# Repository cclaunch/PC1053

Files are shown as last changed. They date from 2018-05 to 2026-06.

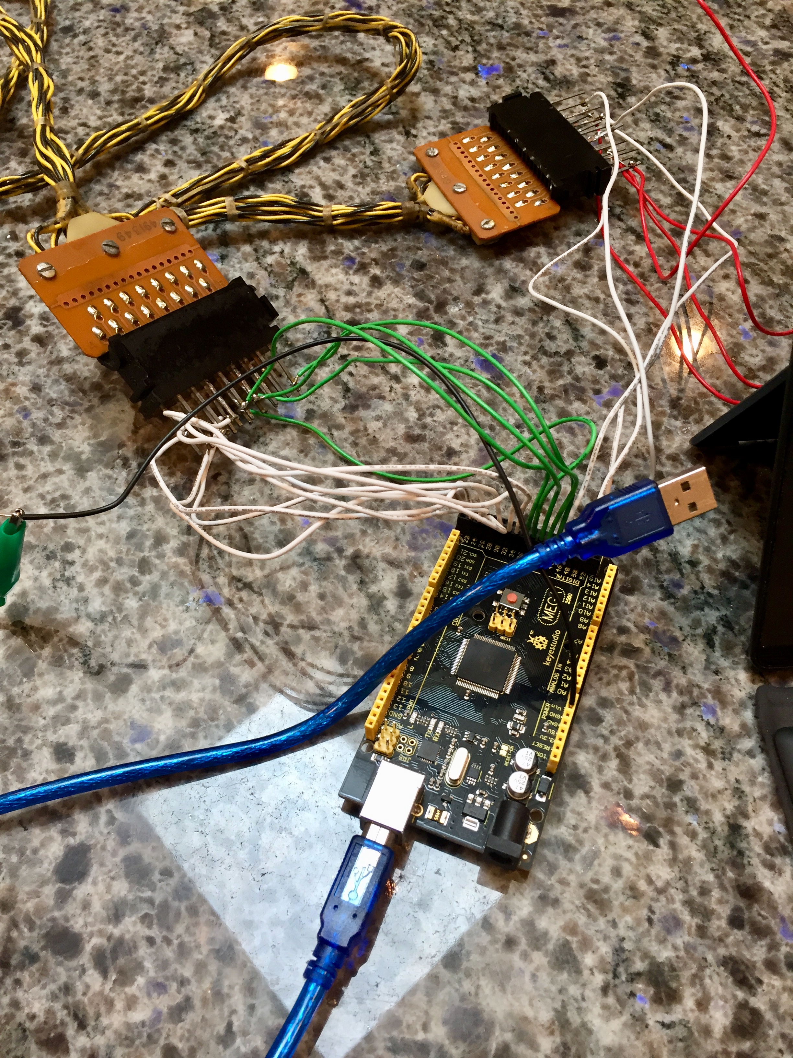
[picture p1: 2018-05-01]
testdriver quick and dirty.jpg

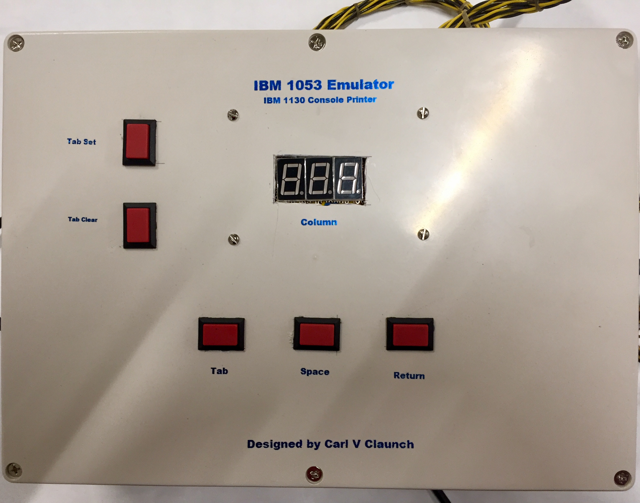
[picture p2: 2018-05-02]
example implementation.jpg

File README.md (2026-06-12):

# PC1053
Emulates an IBM 1053 (print-only I/O Selectric) as used on IBM 1130 and other mainframes of the 1960s

The 1053 attaches to a mainframe with three SMS paddle cards - two carry signals and the third delivers power. This emulator is built around an Arduino Mega 2560 R3, a relay module and some simple circuitry, hooked to three SMS paddle cards. It provides a serial port connection over a USB cable for communicating with a terminal emulator program on a personal computer to display the output that is being 'typed' by the mainframe. 

This emulates the console typeball that is installed on an IBM 1130 system, as well as the APL type ball (988), but can be easily modified to support additional typeballs. The normal typeball has characters that are not in standard ASCII, e.g. ¬ (logical not) and ¢ (cent sign) which can be displayed in UTF8. The APL typeball has many unique characters, thus needs the APL385 Unicode font on the terminal displaying the output. When using the APL typeball, the program looks for eighteen cases where APL software will overtype, using two characters from the typeball with a backspace between them, to form one composite character on paper; the program displays the resultant character instead of the pair. 

Using a terminal emulator that supports UTF8 encoding and ANSI colors provides the most realistic output, since the text will display in either black or red on white background - the text color is selectable by ribbon shift commands from the mainframe to the 1053. The terminal emulator provides a few commands that can be issued to the PC1053 - mainly to set the left and right margins, but also to set, clear and display tab stops that will be in effects and to switch between the normal and APL typeballs. I have found good results using Putty. 

PC1053 operates at approximately the same timing as a 1053, which supported a maximum of 15.5 characters per second and with the high speed carrier return feature would move from right to left edge in just a bit over 1 second. This provides realistic timing on the feedback signals that tell the mainframe when the Selectric mechanism is busy in a print cycle or performing an operation such as shifting case or moving to a new line. 

The device is constructed in a case with a three digit display to show the current column that the typeball/carrier has reached. It has buttons on the front to match the controls on a real 1053 - buttons to Tab, Space and Return, plus tab Set and Clear. This project has a Fritzing diagram of the connections and other circuits, while the physical layout of the case is left as an exercise for the reader. Four MOSFET and transistor circuits are needed to switch the +12V and +48V used with the four feedback signals from the typewriter to the IBM 1130.

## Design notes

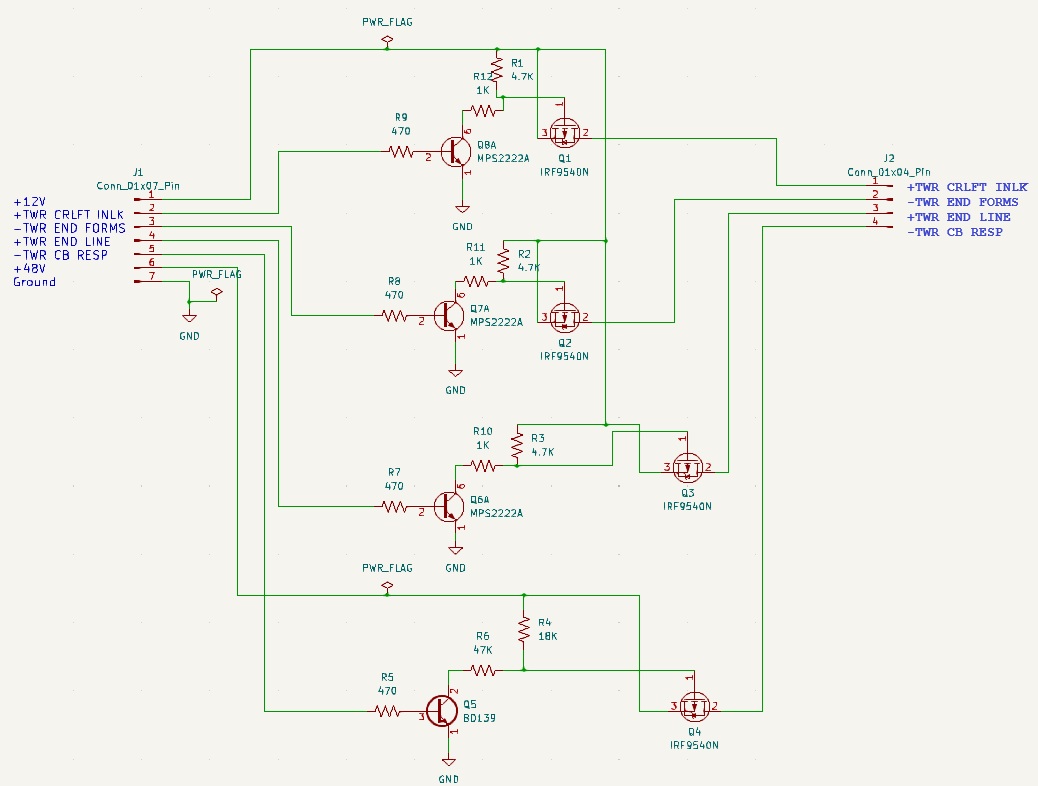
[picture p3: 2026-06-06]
MOSFET schematic.jpg

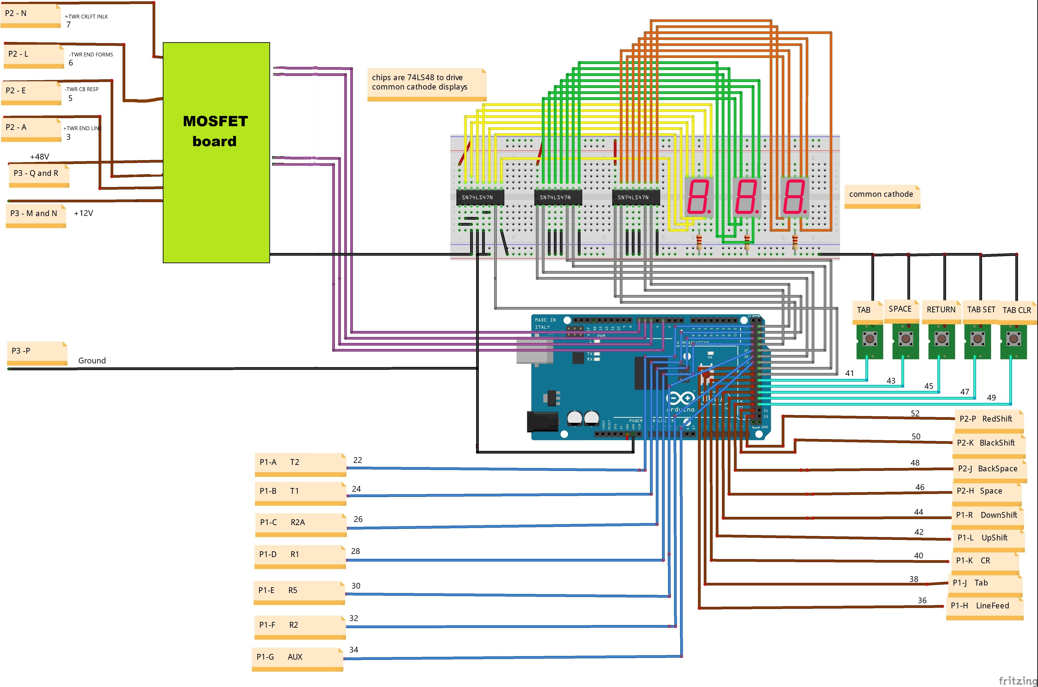
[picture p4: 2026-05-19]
pc1053.jpg

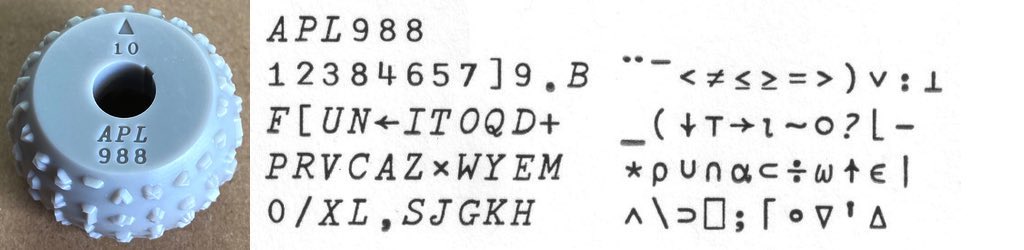
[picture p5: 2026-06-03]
APL988.jpg

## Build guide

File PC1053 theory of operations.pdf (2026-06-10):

## Theory of Operation

1053 Emulator for IBM 1130

Carl V Claunch | 1 | Version 1

Summary

This project created a box that plugs into the IBM 1130 in the place of the 1053 Console Printer that is built into the IBM 1130 System. The box connects via a USB serial cable to a Windows PC running the Putty emulator program.

The Putty program displays all the output exactly as it would appear on the paper in the 1053 printer. It also saves the output in a log file if hardcopy is desired.

The 1053 Emulator is designed to mimic all the behaviors and output of the console printer. The box that contains the emulator provides a three digit display to show the column where the carrier is sitting, buttons to request Return, Tab and Space, and buttons to set or clear a tab stop at the current column.

The other actions that a user could perform on the real 1053 are changing the left and right margins, or switching the golf-ball type element. The margins are changed by typing a command from Putty to the 1053 Emulator

The usual type element for the 1130 is number 969, but ball number 988 can be installed to use the 1130 to run the APL (A Programming Language) system. Another command can be entered through Putty to swtich between the type balls.

1053 Emulator for IBM 1130

Carl V Claunch | 2 | Version 1

The 1053 Console Printer

The console printer is a print only I/O Selectric typewriter. Solenoids are added to the Selectric typewriter mechanism to drive the mechanism. A set of solenoids trigger the following actions:

Space
Backspace
Carrier return/line feed
Line Feed
Tab

Another set of solenoids operate the character selection logic that determine how the ball tilts and rotates to pick one of 44 positions on the gold ball hemisphere. There are two that choose among the four rows of characters - Tilt 1 and Tilt 2. Four select the rotation among 11 columns on the ball - R1, R2, R2A and R5. A final solenoid called Aux is triggered with every request to type a character.

Another two solenoids control the shift mechanism, which spins the golf ball 180 degrees between the two hemispheres. On an office typewriter these are the upper case and lower case characters.

A final two solenoids select the ribbon color, choosing between typing on the upper half of the ribbon or the lower half - as the ribbon is bicolor with red and black ink

Microswitches are also added to the Selectric mechanism to provide feedback to the 1130 about the state of the typewriter. These combine to generate two key feedback signals that indicate when it is safe to request new printing or movement commands as well as when long operations like carrier return have completed.

1053 Emulator for IBM 1130

Carl V Claunch | 3 | Version 1

The Selectric mechanism is motor driven but uses clutches to fire off cycles when it is printing or moving. A print cycle is a 180 degree rotation of the main shaft which occurs when the character selection solenoids activate, moving the ball and flinging it forward to strike the paper through the ribbon.

In addition to typing a character, a 180 degree spin of the operational shaft cycle is used to operate the shift mechanism. When the next character to type is on the other hemisphere, one cycle is required to shift and then a subsequent print cycle does the actual printing of the carrier.

Movements that have a fixed time to operate also take a 180 degree turn of the operational shaft to complete. These are space, backspace and starting a tab movement.

Line feed requires a 360 degree rotation of the operatonal shaft, thus it is considered a long operation. Both tab movement and a carrier return require a variable amount of time to complete, depending upon the starting and ending column for the movement. These are also long operations.

-TWR CB RESPONSE is activated during the short operations and indicates the times when the mechanism is busy and cannot safely accept another request for movement or to type another character. A microswitchon the print cycle shaft opens during part of the rotation. Microswitches on the rear connected to the space and to the backspace mechanisms open while those are occuring. Finally, a microswitch on the mechanism that latches the carrier free so that it can begin a tab movemement will signal that the machine is busy starting to move. ‘

+TWR CRLFT INLK is activated during the long operations. Once the tab has begun and the carrier is latched free of the teeth so it can move, a microswitch on the latch keeps this signal active until the carrier rams into a tab stop which resets the latch as it stops. A microswitch on the

1053 Emulator for IBM 1130

Carl V Claunch | 4 | Version 1

carrier return mechanism latch is turned on when the mechanism latches the return, which drives the carrier to the left under power. When the carrier reaches the left margin, this disconnects the latch and releases the microswitch.

Two additional microswitches activate the signal at the start when the solenoid that requests line feed, carrier return or tab is first triggered, which blocks further requests from the 1130 during the early part of the long operations, until those latches on the return and on the tab mechanisms are active.

Two additional feedback signals are produced. One indicates that their is paper loaded into the typewriter, with a microswitch that the paper holds down. This is -TWR END FORMS. Lastly, a microswitch on the right margin stop is activated when the carrier reaches the right margin position, generating +TWR END LINE to trigger an automatic command from the 1130 to return the carrier and feed a line.

The typewriter menchanism can print at a maximum rate of about 15.6 characters per second if the request for each character is presented by activating the solenoids before the print cycle rotation has come to a stop.

The feedback signal -TWR CB RESPONSE allows the 1130 to send the next request as soon as it is safe to do so, allowing the machine to take continuous rotations without having to start and stop at the 180 degree mark.

Whenever the next character is on a different hemisphere from the one before, a shift cycle has to occur which slows down the machine. The maximum rate can only be achieved with a stream of characters all on the same hemisphere.

1053 Emulator for IBM 1130

Carl V Claunch | 5 | Version 1

The printer uses paper forms with pin feed holes on the two edges, with the typewriter tractor mechanism moving the forms though the machine reliably. Boxes of paper forms in this size are no longer available.

The line width is 120 columns, although the user can adjust the left and right margins to a narrower range. An indicator on the front of the printer shows the current column where the carrier is sitting.

Like any Selectric based typewriter, it provides tab stops to allow the softare to move the carrier to predetermined columns. These are set or cleared by manually moving the carrier to the desired column then turning the lever on the front of the printer to set or clear the tab stop.

The front of the printer also has three buttons that allow the user to trigger a carrier return/line feed, tab the carrier to the next tab stop, or space the carrier one column to the right.

The front of the printer also hosts a set of 16 toggle switches, named the Console Entry Switches. These are not related to the console printer at all, other than being mounted on the printer’s front panel

1053 Emulator for IBM 1130

Carl V Claunch | 6 | Version 1

The 1053 Emulator hardware

The emulator is constructed around an Arduino Mega 2560 controller board. It detects the signals from the 1130 that fire the various solenoids and it generates the four feedback signals to the 1130.

The 1053 has 48V applied to one side of each solenoid and the other side is connected to the controller logic inside the 1130. The controller logic is like an open collector gate - it either grounds the signal or leaves it untouched.

This is fortunate, because the Arduino can connect to the same logic gates but use a pullup resistor to +5V instead of dealing with 48V. When the controller logic pulls a line to ground, the Arduino sees its value drop from logic high to logic low. No interface circuitry is required for all the solenoid signals.

The feedback signals, on the other hand, must deliver a higher voltage to a switch debouncer circuit in the 1130 controller logic. Three of the signals have +12V running through the microswtiches, but the -TWR CB RESPONSE microswitches are fed with 48V.

The Arduino cannot handle these voltages, so I have a switching board that is driven by a 0-5V Arduino output and controls a MOSFET switch which acts almost exactly like the microswithces. The only different is that there is no switch bounce. Four circuits switch the four feedback signals.

1053 Emulator for IBM 1130

Carl V Claunch | 7 | Version 1

The box also contains five pushbuttons hooked to the Arduino, to activate the Tab Set, Tab Clear, Return, Tab and Space functions. Finally, the box has a board that drives three seven segment displays, using BCD to 7 Segment decoder chips (74LS47) to produce the digits.

Cables run from the box to connect into the 1130. One cable brings signals to an SMS paddle card (PF1), another cable brings signals to an SMS socket (PF2). The third is an SMS power paddle card that would deliver multiple voltages to the 1053. We ignore the 120V that the typewriter needs for its motor, but do use the +48V, +12V and ground lines.

1053 Emulator for IBM 1130

Carl V Claunch | 8 | Version 1

High level view of the Arduino code

The main loop first checks to see if data is arriving over the USB serial link, which it assembles until we reach eight bytes with a newline at the end. This is interpreted and if it is validly formatted, action is taken.

The valid incoming data can be a TS ###, TC ###, LM ###, or RM ### to set or clear tab stops or the left or right margin to column ###. Two other valid statements are TABS = and TYPE # which display all columns with tabs set or switches between type balls A or N.

All of the incoming signals from the 1130 controller logic are configured as inputs with a pullup resistor to 5V. The controller logic will pull the signal to ground to assert the request to activate a solenoid in the 1053.

Any request to type a character involves some number of selection solenoids being activated but always includes the AUX signal. Just as with the 1053 mechanism, the first selection signal that is asserted triggers a 65 millisecond print cycle.

The code waits until we are 5 ms into the print cycle so that other selection solenoid requests can arrive, as they might lag slightly from the first signal to be detected. At this time, the combination of selection solenoid requests is interpreted to determine what character on the type ball is to be printed.

1053 Emulator for IBM 1130

Carl V Claunch | 9 | Version 1

The selection solenoids T2, T1, R1, R2, R2A, R5 and AUX are used to look up an index in a tilt-rotate table.That index points to which of the 44 positions - four rows of tilt 0-3, eleven columns of rotate -5 to +5 - has the intended character.

Depending on which typeball (969 - normal, or 988 - APL) is installed and whether the ball is turned to the upper case or lower case hemisphere, we look in one of four character tables to pick up the unicode character.

At specific times in the 65 ms print cycle, the feedback signal -TWR CB RESPONSE is asserted and then deasseerted. The unicode character we picked up from the tables is stored in a line buffer at the current column position of the typeball carrier.

When we begin a new line we zero out a buffer that has entries for all 120 columns that can be typed upon by the 1053.

This buffer exists to support overtyping, where characters are typed in a column more than once. If the second character typed in the same column are different, then the ‘ink’ from each is left on the paper which forms a composite impression.

When using the APL type ball, we support overtyping for eighteen known cases that APL software produces. Otherwise, backspacing and then typing a character simply replaces the old with the new. The composite characters produced are:

⍱⍲⍒⍋⌽⍉⊖⍟⌶⍫⍎⍕⍀⌿⍝⍞!⌹

1053 Emulator for IBM 1130

Carl V Claunch | 10 | Version 1

Composite impressions can be used to obscure sensitive data, for example, but they can also be used to form a character that does not exist on the type ball. With only 88 positions on a type ball, 36 of which are necessary just to cover the alphabet and numeric digits, composite characters may be needed to support a broad character set requirement for some software that exceeds the capacity of a typeball.

Thus, every time we print at a column, the character is added to the buffer if it was empty. If the buffer already recorded a character had been previously printed there, we can check for the eighteen special cases.

The way that an overtype is accomplished on the 1053 is to use the backspace movement to shift the typeball carrier leftward to lower numbered columns up to the minimum of the left margin column. Then the additional character is typed.

When a space movement occurs with the 1053, it just moves one column to the right, leaving the paper underneath undisturbed. In the emulator, we have to print a space character the first time we reach a column moving from left to right, but if we had backspaced and then space forward, we do NOT want to blank out what was previously there.

The code checks the line buffer to see if anything had been printed in the column; if so, we just repeat typing the data in the buffer while we move the cursor one column forward.

1053 Emulator for IBM 1130

Carl V Claunch | 11 | Version 1

This supports the ability to edit a line by moving back and forward using backspace and space movement commands, leaving what is viewed on the screen appearing just as they were. Any typing that happens in a column where we previously typed is used to form a composite on the screen.

The movement requests space, backspace and tab will also kick off a print cycle of 65 ms, but without the AUX solenoid being fired, we don’t have a character to ‘type’ on the screen. We change the column where the typeball sits, retyping anything in columns we pass over, if characters had been typed there.

The code emits space and backspace characters to the terminal emulator program, or retypes a column, so that the screen matches what we would see on the paper on a 1053.

We use a fast search method to look at the byte array, 120 bytes for the 120 columns, searching for the first non-zero byte. That is the location of the next tab stop. We space over to that column to finish the tab movement or retype from the buffer as appropriate.

Solenoid assertions for carrier return/line feed, tab, or line feed also trigger a long cycle, which typically extends past the 65ms of the primary print cycle. At fixed times during the long cycle, the +TWR CRLFT INLK feedback signal is asserted and then deasserted.

1053 Emulator for IBM 1130

Carl V Claunch | 12 | Version 1

The time it will take to finish the long cycle depends on the operation and also both the current column number and the destination column number. A carrier return from the right side takes longer than if it is issued only ten columns to the right of the margin. A tab duration depends on how many columns we have to pass from the current column to the first one that has a tab stop set. Line feed takes a fixed amount of time to occur.

This is calculated when we start the long cycle and used to control the deassertion of the +TWR CRLFT INLK feedback signal

Activations for the Shift to Upper or Shift to Lower solenoids trigger a 65 ms print cycle, but without the AUX solenoid asserted, nothing is typed. We simply record the hemisphere that is reached as this is used during the character table lookups when printing.

Asserting the Shift to Red or Shift to Black solenoids does NOT trigger a print cycle or provide any feedback signals. It causes the code to send an ANSI Color sequence to the Putty terminal program which changes the text color to red or black.

On the 1053, the user slides levers to set the left and right margins. The left margin is the point where the typeball carrier stops when doing a carrier return. It is the point beyond which we cannot backspace. The right margin is where the +TWR END LINE feedback signal is asserted if the carrier reaches that column.

1053 Emulator for IBM 1130

Carl V Claunch | 13 | Version 1

The controller logic in the 1130 will immediately trigger a carrier return/line feed cycle by assering that solenoid when the end of line feedback signal is on. The controller marks the typewriter busy until the return has finished based on the feedback signal +TWR CRLFT INLK going low.

However, if the user somehow manages to drive print requests when we have reached the right margin, the code does not advance the column, it backspaces and erases whatever character we tried to type. This matches how the 1053 behaves in the same circumstances.

The last feedback signal from the 1053 that we control is -TWR END FORMS which is asserted low if the paper has run out on the 1053. The controller logic will not type or move the carrier when this is asserted and a FORMS CHECK lamp on the console of the IBM 1130 will illuminate..

If the 1053 Emulator is powered down, the 1130 system sees the -TWR END FORMS signal as asserted and lights the FORMS CHECK lamp. During the setup part of the code initialization, we deassert this, extinguishing the lamp.

1053 Emulator for IBM 1130

Carl V Claunch | 14 | Version 1

Special techniques used in the code

We make use of direct port register access rather than using the slower digitalRead and digitalWrite statements. Refer to a port map for the Arduino Mega 2560 to see which registers and bits of the Microchips ATmega2560 processor chip are associated with each of the Arduino pins.

I used the traditional Arduino statements to set the input or output mode for the pins, but then I directly access the ports to read or write. For a read, I examine the specific bit of the associated port, usng macros for readability:

#define readAUX !(PINC & (1<<3))

For writes, I either set or clear the specific bit in the associated register to set the Arduino pin high or low. I set up macros to do this, for example:

#define highEOL | PORTE |= (1<<5)

#define lowEOL | PORTE &= ~(1<<5)

Rather than looping through an array of 120 locations looking for the next tab stop, I used a fast search that moves through a byte array by fetching doublewords at a time until the doubleword is non-zero, then determining which of the bytes inside has the first non-zero value.

1053 Emulator for IBM 1130

Carl V Claunch | 15 | Version 1

I do make use of character pointer arithmetic to index into arrays, thus array[index] or array+index is equivalent. Unicode characters can take 1 to 4 bytes of storage, thus a character array such as the table of characters on the typeball is not simply 88 bytes long. The location of a specific character in the array is not simply an integer index.

In fact the index into the array is to a byte, not to character boundaries. For example, if the first three characters in the array are a four byte Unicode, a 1 byte Ascii and a four byte Unicode, then the index of the fourth character is 8 - there were nine bytes consumed for the first three characters.

I have some helper routines that will scan through a Unicode character array and return the byte index into the array of the nth character. Asking it for the fourth character would return a byte index 8 based on the example in the prior paragraph.

Another helper routine is given the starting byte in the character array and copies the character at its correct length into a temporary five byte long character field called tempchar which is zero terminated. Thus we always print using tempchar as it will have the proper length string of bytes for the Unicode character, anything from 1 to 4 with a terminating null character.

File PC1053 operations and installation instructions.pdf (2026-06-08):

## Operations and Installation Instructions

1053 Emulator for the IBM 1130

Carl V Claunch | 1 | Version 1

1053 Console Printer on the IBM 1130 System

The IBM 1130 System was announced and delivered in 1965. The system comes with a console that has a keyboard and a printer, along with controls and display lights. The console printer is a print only I/O Selectric typewriter.

The printer uses paper forms with pin feed holes on the two edges, with the typewriter tractor mechanism moving the forms though the machine reliably. Boxes of paper forms in this size are no longer available.

The line width is 120 columns, although the user can adjust the left and right margins to a narrower range. An indicator on the front of the printer shows the current column where the carrier is sitting.

As each character is typed the carrier advances to the right until it reaches the right margin, when a bell will ring and the 1130 will automatically move the carrier back to the left margin and advance the paper one position.

A type element (golfball) is installed on the carrier to provide the 88 characters that can be printed. The normal ball for the IBM 1130 is numbered 969 just under the top latch, although variations were used for some non-US customers.

The 1053 has a dual color ribbon, allowing the selection of either black or red type to be printed on the paper.. This is under software control.

Like any Selectric based typewriter, it provides tab stops to allow the softare to move the carrier to predetermined columns. These are set or cleared by manually moving the carrier to the desired column then turning the lever on the front of the printer to set or clear the tab stop.

1053 Emulator for the IBM 1130

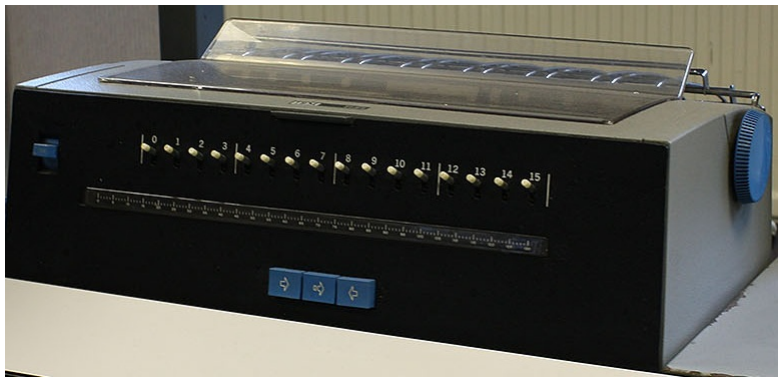
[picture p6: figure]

Carl V Claunch | 2 | Version 1

The 1053 has a high speed carrier return feature installed which returns from the right side to the left margin in roughly one second. Line feed operations move the paper up one or two lines at a time - selectable by a lever on the printer - in under a second. The typewriter can produce print at a rate of up to 15.6 characters per second.

The front of the printer also has three buttons that allow the user to trigger a carrier return/line feed, tab the carrier to the next tab stop, or space the carrier one column to the right.

The front of the printer also hosts a set of 16 toggle switches, named the Console Entry Switches. These are not related to the console printer at all, other than being mounted on the printer’s front panel

image modified from- Martin Skøtt -File:IBM 1130 concole.ms.jpg (https://commons.wikimedia.org/wiki/File:IBM_1130_concole.ms.jpg) [accessed 2026-06-05]. License/note: CC BY-SA 2.0.

Three cables run from the printer down through the 1130 to plug into connector blocks. Two are for the signals between the 1130 and 1053, the third carries power to the console printer.

1053 Emulator for the IBM 1130

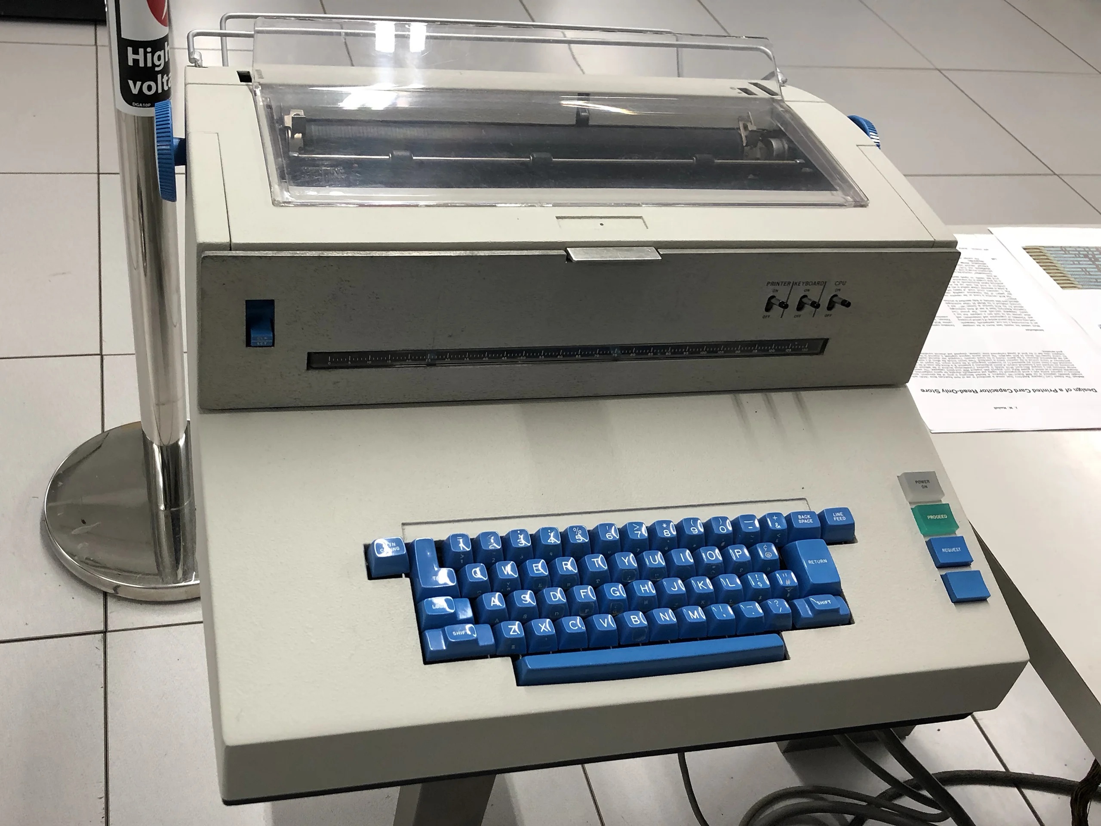
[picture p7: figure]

Carl V Claunch | 3 | Version 1

IBM used the same mechanism for the primary operator consoles of their System 360 mainframes, introduced at about the same time. That 1052 had a slightly different case, without the console entry switches of the 1130 and had a keyboard attached.

The keyboard was not a Selectric typewriter part, it was the keyboard used in the 029 Keypunch. It shared the case but was unrelated to the printer portion of the 1052. The same keyboard mechanism is on the IBM 1130 but not physically connected to the console printer.

image: ComputerGeek7066 - File:IBM 1052.jpg (https://commons.wikimedia.org/wiki/File:IBM_1052.jpg) [accessed 2026-06-05]. License/note: CC BY-SA 4.0 (cropped).

1053 Emulator for the IBM 1130

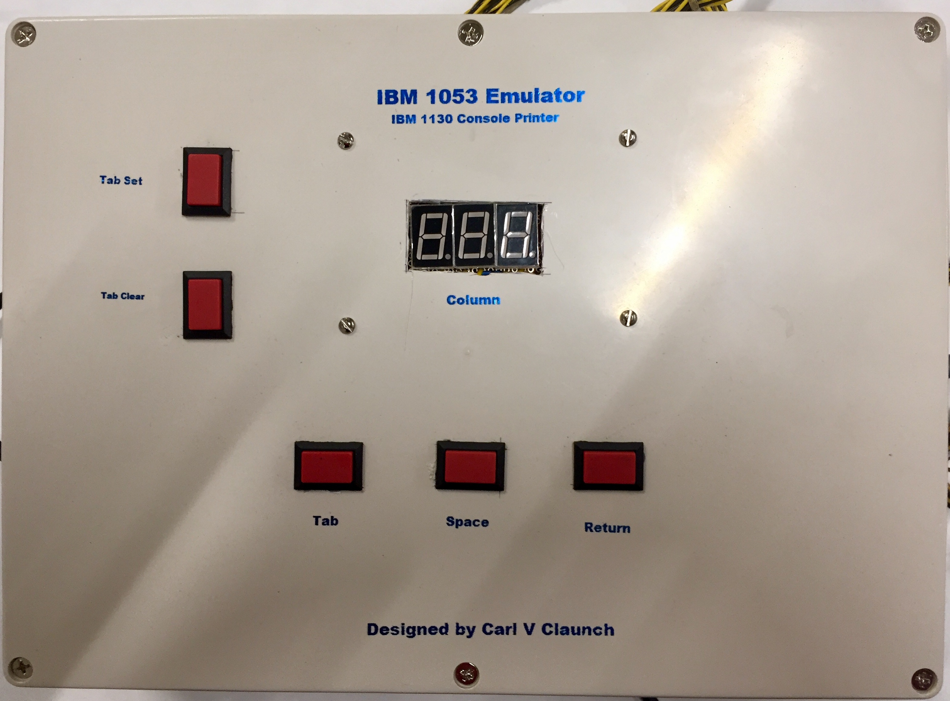
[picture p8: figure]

Carl V Claunch | 4 | Version 1

Overview of the 1053 Emulator

The emulator consists of a box that sits on top of the 1130 system and connected by a USB serial cable to a computer that runs a terminal program where the output of the console printer is displayed and recorded.

The box has a three digit display that shows the column where the carrier is sitting at the moment. Buttons across the bottom allow the user to command the printer to space one column to the right, move the carrier to the next column on the right that has a tab stop set, or to return the carrier to the left and advance the paper one line.

1053 Emulator for the IBM 1130

Carl V Claunch | 5 | Version 1

Buttons on the left will set or clear the tab stop at the current column as displayed on the three digit display. Other interactions are supported by commands through the USB serial cable.

A menu is printed when the emulator starts up, listing the commands that it will recognize when typed on the computer emulator program that displays the output.

The left and right margins are set by commands, otherwise they default to column 1 and column 120. The emulator program displays output in red or black text, based on how the 1053 would be typing at the moment.

For convenience, commands are provided to set or clear tabs by entering the column number, rather than having to space the carrier over to the desired column. Another command will display all the tabs that are set.

One additional type element can be used with the IBM 1130, to run
APL (A Programming Language). The ball has 988 on the top near the lever and contains the specialized characters that are used in APL. To switch between typeballs, the command TYPE # is issued, where # is N for the 969 ball and A for the 988 ball.

Some of the characters used in APL are composite, formed by typing one character from the ball, backspacing, and typing over it with another character from the ball. The display will show the composite character just as it would have been produced by ink overtyped on ink using paper in the 1053.

1053 Emulator for the IBM 1130

Carl V Claunch | 6 | Version 1

Starting the Putty emulator program

The 1053 Emulator has been tested with the free Putty terminal emulator running on Windows. It requires that the WIndows system has installed the free APL 385 Unicode truetype font, then configure the terminal to use that font.

Assuming you have configured Putty and saved the configuration, you load that saved config to start the program. The configrution also specifies that a log file is saved with the output. The file does not save colors but otherwise it will match the text shown on the screen.

Generally, the user will set the left and right margins via commands, set any tab stops expected by software and then start the 1130 software.

The 1053 Emulator is powered by the USB connection from the computer running Putty. When it is not on, the FORMS lamp on the 1130 will light, indicating that the 1053 is not able to print because it does not have paper loaded. As soon as the Emulator powers up, the FORMS lamp will turn off.

1053 Emulator for the IBM 1130

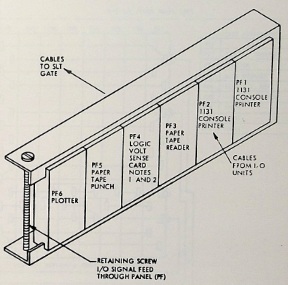
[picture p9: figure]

Carl V Claunch | 7 | Version 1

Installing the 1053 Emulator signal cables

Inside the 1130, the three cables from the 1053 printer are hooked to connector blocks. The upper connector block is where signals are connected from certain peripherals including the 1053. The lower connector block is where the power cables for the peripherals attach.

The devices that use these connector blocks are older designs that use the 1950s generation Standard Modular System (SMS) rather than the Solid Logic Technology (SLT) of the 360, 1130 and 1960s era devices.

The connector on the cable is an SMS paddle card, which has the same kind of pads on the end as SMS logic cards from machines like the 1401. A female version exists, which is the socket that the logic cards fit into, which can fit on the end of a cable instead of the paddle card. For the 1053, there are two signal cables. PF1 ends in an SMS paddle card (male) while PF2 has an SMS socket (female) on its end.

1053 Emulator for the IBM 1130

Carl V Claunch | 8 | Version 1

The signal connector block has assigned location for each peripheral, with the two rightmost locations used for the 1053. The rightmost postion has an adapter installed, so that the PF1 paddle card plugs into one side and a paddle card from the 1130 processor plugs into the rear side. The second position is where the PF2 SMS socket fits, with a paddle card from the 1130 plugged into the socket from the rear.

First, the SMS paddle card from the 1130 logic is pulled out of the PF2 SMS socket from the rear. We unplug the PF1 SMS paddle card from the adapter. The bolt on the left is removed and the PF2 SMS socket is slid out of the bracket to the left to remove the 1053 cables.

The 1053 Emulator PF2 SMS socket is slid into the bracket, the PF1 paddle card is inserted into the adapter in in the rightmost position, and the bolt is replaced in the connector block. The SMS paddle card behind the PF2 socket is inserted from the rear to complete the installation of the signal cables.

1053 Emulator for the IBM 1130

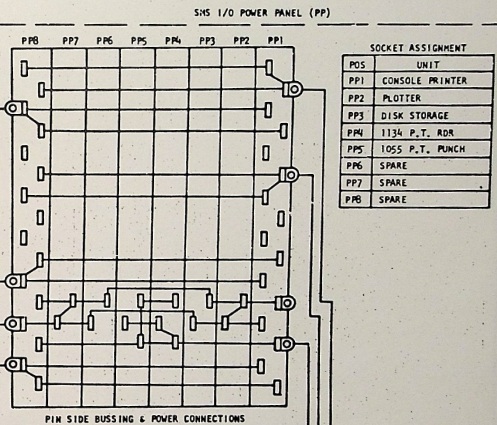
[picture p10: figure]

Carl V Claunch | 9 | Version 1

Installing the 1053 Emulator power cable

The power connections use a modified version of the SMS paddle card. These have larger combined pads to carry more current, as well as having a notch cut into them that blocks ordinary paddle cards from fitting into the power connector block. The power connector block has a metal bar across the span that prevents signal cards from being inserted.

The power connector block also has assigned locations for each device, with the 1053 assigned to the rightmost socket.

1053 Emulator for the IBM 1130

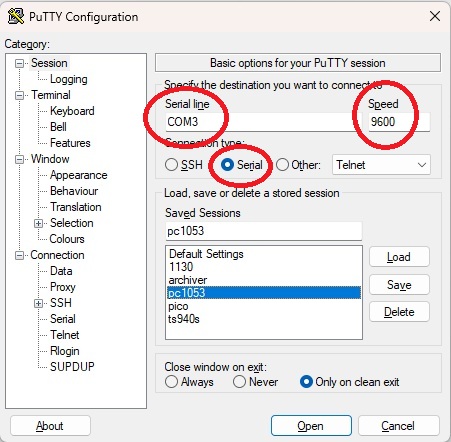
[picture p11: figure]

Carl V Claunch | 10 | Version 1

Configuration of Putty

On the main configuration screen, set the connection type to Serial, the speed to 9600 baud and use whatever COM port that the 1053 Emulator shows up with.

1053 Emulator for the IBM 1130

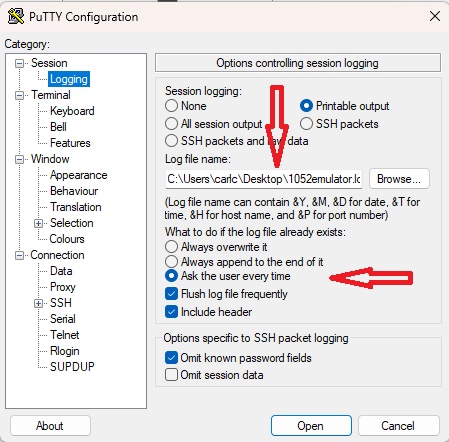
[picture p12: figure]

Carl V Claunch | 11 | Version 1

Next, go to the logging screen and choose a file location and name for the log file. Also select the option to ask the user for how to handle it when the log file already exists from a prior run. .

1053 Emulator for the IBM 1130

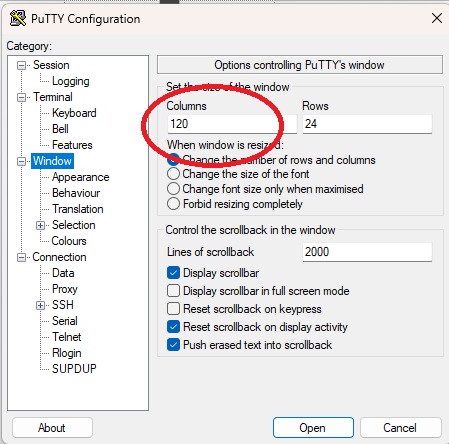
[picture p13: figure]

Carl V Claunch | 12 | Version 1

Select the Window category and configure the terminal to 120 column width.

1053 Emulator for the IBM 1130

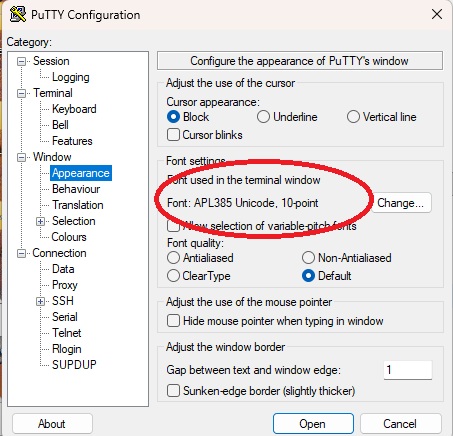
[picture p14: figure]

Carl V Claunch | 13 | Version 1

The appearance category is where you change the font for the terminal window to use the APL385 Unicode truetype font, at 10 point size.

1053 Emulator for the IBM 1130

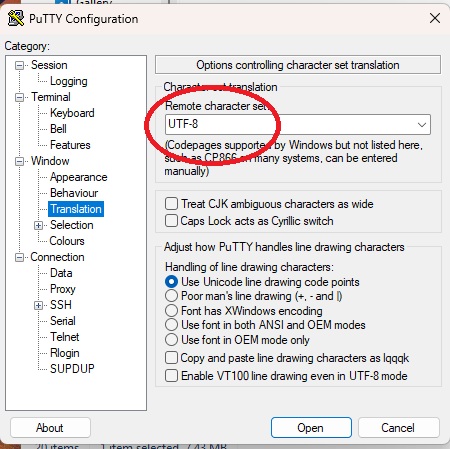
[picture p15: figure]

Carl V Claunch | 14 | Version 1

Configure the Translation category to set the character set to UTF-8 which is how the 1053 Emulator is emitting characters.

1053 Emulator for the IBM 1130

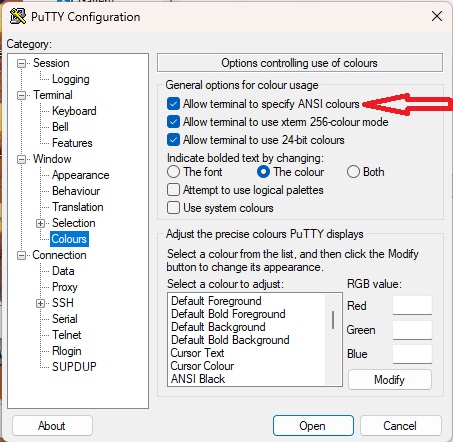
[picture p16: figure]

Carl V Claunch | 15 | Version 1

The Colors category should set the window to use ANSI Colors which is how the 1053 Emulator controls the text color.

1053 Emulator for the IBM 1130

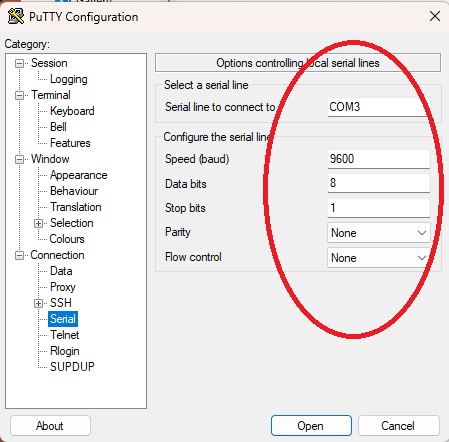
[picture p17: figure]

Carl V Claunch | 16 | Version 1

The final category to look at is Serial. Make sure that the link is set up for 9600 baud, 8 data bits, 1 parity bit, no parity and no flow control.

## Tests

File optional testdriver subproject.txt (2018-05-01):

Optional testbed for PC1053

Using a second Arduino Mega 2560 and some SMS sockets, you can use the testdriver.ino file and its Fritzing diagram to put the PC1053 through its paces without plugging into an actual mainframe. It provides the ability to send every command and character that the mainframe can produce; it even provides a 2 ms skew in setting of the tilt/rotate lines to verify that this device can handle slight variations in timing from the mainframe.

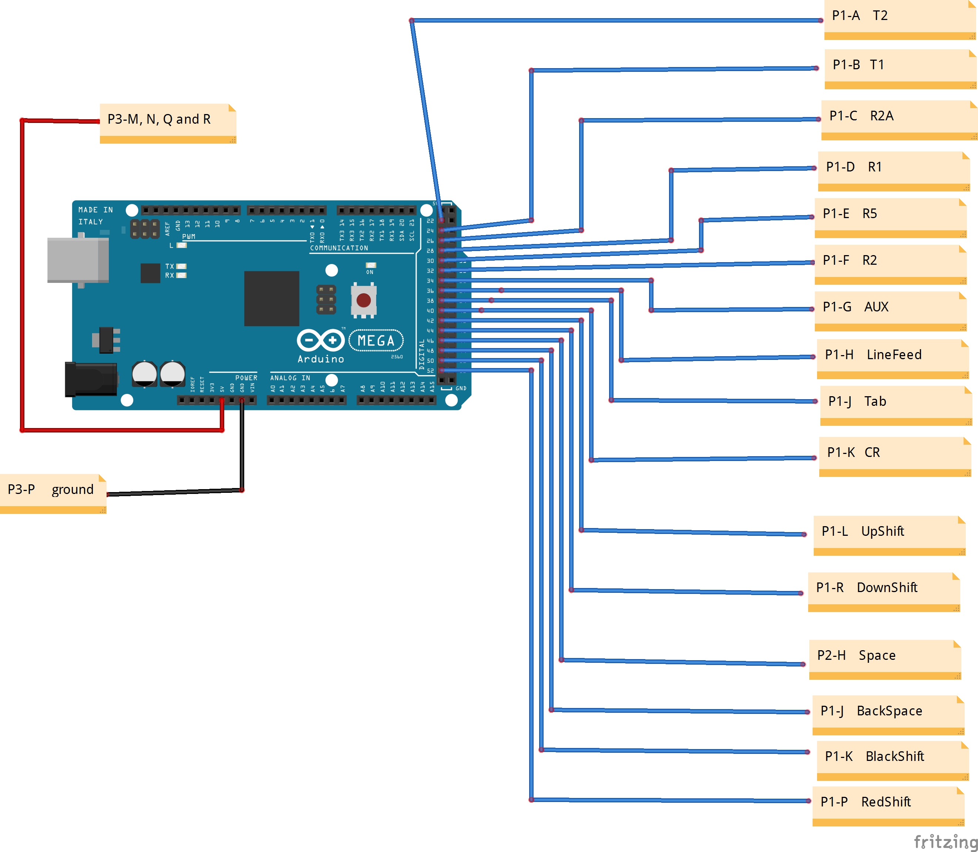
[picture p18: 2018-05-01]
testdriver.jpg

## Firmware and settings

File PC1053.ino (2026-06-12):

// PC1053 project to emulate an IBM 1053 Console Printer when hooked to an IBM 1130 or IBM 1800 computer system
//
//    Carl V Claunch
//
// repository on Github https://github.com/cclaunch/PC1053
//
// drives an Arduino Mega 2560 hooked to MOSFET switches, 7 segment display hardware, pushbuttons, and SMS style paddle
// connectors that plug into the 1130 or 1800. One of the paddle connectors provides power (ground, +12V and +48V) to
// the 1053, which is an I-O Selectric mechanism based around a Selectric 1 typewriter using solenoids and microswitches
// to interface it to a computer. Commonly used in the 1960s with the 1130, 1800 and as the main console for S/360 systems
//
// uses direct port access which ties this to the specific Arduino model (Mega 2560)
//
// connect via USB serial port at 9600 baud 8 n 1 1 using UTF-8 encoding and ANSI Colors
//
// supports simple commands from the serial terminal
//  LM nnn     
//       sets the column for the left margin
//
//  RM nnn
//       sets the column for the right margin
//
//  TS nnn
//       sets a tab stop at column nnn
//
//  TC nnn
//       clears a tab stop at column nnn
//
//       NOTE for all commands with nnn, a three digit column number with leading zeroes if needed
//
//  TABS =
//    displays all the column numbers where a tab stop is set 
//
//  TYPE t
//    switches between normal and APL typeball  NOT YET SUPPORTED
//    *******   t is either N for normal or A for APL typeball

#include <stdint.h>
#include <stddef.h>

// global defines
#define SelectT2      22
#define SelectT1      24
#define SelectR2A     26
#define SelectR1      28
#define SelectR5      30
#define SelectR2      32
#define SelectAux     34
#define LineFeed      36
#define Tab           38
#define CrLf          40
#define UpShift       42
#define DownShift     44
#define Space         46
#define BackSpace     48
#define BlackShift    50
#define RedShift      52
#define TwrEOL         3
#define TwrCBResp      5
#define TwrEndForms    6
#define TwrCRLFTinlk   7
#define OnesA         23
#define OnesB         25
#define OnesC         27
#define OnesD         29
#define TensA         31
#define TensB         33
#define TensC         35
#define TensD         37
#define HundredsA     39
#define TabButton     41
#define SpaceButton   43
#define CRButton      45
#define TabSet        47
#define TabClr        49

// define the sequences to print for ribbon color control
#define ESC     '\x1b'
#define OPEN    '['
#define BLACK   "30;1"
#define RED     "31;1"
#define WHITEBG "107"
#define BOLD    "1"
#define GREEN   "32;1"
#define END     'm'

// set up the special Zero Width Joiner unicode character
char  ZWJ[]  =  "\u200D ";

// define states for BCD 7seg controllers
//  LOW is LOW
//  HIGH is HIGH

// define states for MOSFET drivers
// HIGH is LOW
// LOW is HIGH

// direct access replacement for digitalRead statements
#define readT2   !(PINA & (1<<0))
#define readT1   !(PINA & (1<<2))
#define readR2A  !(PINA & (1<<4))
#define readR1   !(PINA & (1<<6))
#define readR5   !(PINC & (1<<7))
#define readR2   !(PINC & (1<<5))
#define readAUX  !(PINC & (1<<3))
#define readLF   !(PINC & (1<<1))
#define readTAB  !(PIND & (1<<7))
#define readCRLF !(PING & (1<<1))
#define readUP   !(PINL & (1<<7))
#define readDN   !(PINL & (1<<5))
#define readSP   !(PINL & (1<<3))
#define readBSP  !(PINL & (1<<1))
#define readBLK  !(PINB & (1<<3))
#define readRED  !(PINB & (1<<1))
#define readTBUT !(PING & (1<<0))
#define readPBUT !(PINL & (1<<6))
#define readRBUT !(PINL & (1<<4))
#define readSBUT !(PINL & (1<<2))
#define readCBUT !(PINL & (1<<0))

// direct port access to replace digitalWrite statements
#define highEOL  PORTE |= (1<<5)
#define lowEOL   PORTE &= ~(1<<5)
#define highCBR  PORTE |= (1<<3)
#define lowCBR   PORTE &= ~(1<<3)
#define highEOF  PORTH |= (1<<3)
#define lowEOF   PORTH &= ~(1<<3)
#define highCRLFT PORTH |= (1<<4)
#define lowCRLFT PORTH &= ~(1<<4)
#define onONEA   PORTA |= (1<<1)
#define offONEA  PORTA &= ~(1<<1)
#define onONEB   PORTA |= (1<<3)
#define offONEB  PORTA &= ~(1<<3)
#define onONEC   PORTA |= (1<<5)
#define offONEC  PORTA &= ~(1<<5)
#define onONED   PORTA |= (1<<7)
#define offONED  PORTA &= ~(1<<7)
#define onTENA   PORTC |= (1<<6)
#define offTENA  PORTC &= ~(1<<6)
#define onTENB   PORTC |= (1<<4)
#define offTENB  PORTC &= ~(1<<4)
#define onTENC   PORTC |= (1<<2)
#define offTENC  PORTC &= ~(1<<2)
#define onTEND   PORTC |= (1<<0)
#define offTEND  PORTC &= ~(1<<0)
#define onHUNA   PORTG |= (1<<2)
#define offHUNA  PORTG &= ~(1<<2)

// direct port access to speed up Serial.available()
#define Incoming (UCSR0A & (1 << RXC0))

// define timers for short and long cycles
long Ctime = 0;
long Ltime = 0;

// save commands for typewriter
int doT2;
int doT1;
int doR2A;
int doR1;
int doR2;
int doR5;
int doAux;
int doTab;
int saveTab;
int doSpace;
int saveSpace;
int doBackSpace;
int saveBackSpace;
int doCrLf;
int saveCrLf;
int doLineFeed;
int saveLineFeed;
int doUpShift;
int saveUpShift;
int doDownShift;
int saveDownShift;
int doBlackShift;
int saveBlackShift;
int oldBlackShift;
int doRedShift;
int saveRedShift;
int oldRedShift;
int doSpaceButton;
int oldSpaceButton;
int doTabButton; 
int oldTabButton; 
int doCRButton;
int oldCRButton;
int doTabSet;
int doTabClr;

// define states for state machines
#define Idle  0
#define Wait  1
#define Grab  2
#define Trig  3
#define Break 4
#define Emit  5

// define state machines
int Cstate = Idle;
int Lstate = Idle;
int oldCstate = Idle;
int oldLstate = Idle;

// working variables
int anychar =     0;
int anycommand =  0;
int anyop =       0;
int Caps =        0;
int Cols =        1;
int oldCols =     1;
int lmargin =     1;
int rmargin =   120;
int aplball =     0;
long leap =       0;
long retreat =    0;
long drop =       0;
int RedRibbon =   0;
int hemisphere =  0;

char tempchar[5];

// select code table
// int Cselect[44] = {15, 6,  7, 12, 13,  4,  5,  9,  8, 31,
//                   22, 23, 28, 29, 20, 21, 25, 24, 38, 39,
//                   44, 45, 36, 37, 41, 40, 63, 54, 55, 60,
//                   61, 52, 53, 57, 56, 49, 48, 47, 33, 32,
//                   17, 16, 1, 0};

// inverse select code table, built from above table
int TRselect[64] = {43,42,44,44,5,6,1,2,8,7,
                    44,44,3,4,44,0,41,40,44,44,
                    14,15,10,11,17,16,44,44,12,13,
                    44,9,39,38,44,44,22,23,18,19,
                    25,24,44,44,20,21,44,37,36,35,
                    44,44,31,32,27,28,34,33,44,44,
                    29,30,44,26};
              
// Upper case character table
char Hchar[] = "ABCDEFGHIJKLMNOPQRSTUVWXYZ(+<¬);*'\"|=_?:>!%¢";
              
// Lower case character table
char Lchar[] = "ABCDEFGHIJKLMNOPQRSTUVWXYZ1234567890#/-,&$@.";

// upper case APL (988 ball) character table
char AHchar[] = "⍺⊥∩⌊ε▁∇∆⍳∘'⎕∣⊤○⋆?⍴⌈∼↓∪⍵⊃↑⊂\"¯>≥\=≤<≠∨∧)\\→;-(÷:";

// lower case APL (988 ball) character table
char ALchar[] = ".HIGFEDBC[QRPONMKLYZXWVUST]8976542301,←/+J×A";

// helper indexes
char * Uindex[44];
char * Lindex[44];
char * AUindex[44];
char * ALindex[44];

// line buffer to support overtyping
// this holds the select code that was typed into a column previously,
int buffer[120];

// lookup table for APL codes that combine to a print a composite glyph
// has three select codes for each, the two that are typed by the 1130
// and the code for the new glyph
int APLlookup[18][3] = { 157, 140, 201,  // or + tilde
                         150, 140, 202,  // and + tilde
                         106, 129, 203,  // del + stile
                         110, 129, 204,  // delta + stile
                         129, 121, 205,  // stile + circle
                         121, 148, 206,  // circle + slope
                         121, 118, 207,  // circle + bar
                         121, 122, 208,  // circle + star
                         107, 130, 209,  // uptack + downtack
                         106, 140, 210,  // del + tilde
                         107, 132, 211,  // uptack + null
                         130, 132, 212,  // downtack + null
                         148, 118, 213,  // slope + bar
                         33,  118, 214,  // slash + bar
                         108, 132, 215,  // cap + null
                         123, 124, 216,  // quote + quad
                         123,  16, 217,  // quote + dot
                         124, 102, 218  // quad + divide
};

char composite[] = "⍱⍲⍒⍋⌽⍉⊖⍟⌶⍫⍎⍕⍀⌿⍝⍞!⌹";

// tab stop table
byte stops[120];

// helper function
// Returns the raw byte index for the N-th character in a UTF-8 array
int getUtf88ByteIndex(const char* str, int targetCharIndex) {
  int byteIdx = 0;
  int charCount = 0;

  while (str[byteIdx] != '\0') {
    if (charCount == targetCharIndex) {
      return byteIdx; // Found the start of our target character
    }
    
    unsigned char b = str[byteIdx];

    // Determine how many bytes this character uses
    if ((b & 0x80) == 0x00)        byteIdx += 1; // 1-byte ASCII
    else if ((b & 0xE0) == 0xC0)   byteIdx += 2; // 2-byte character
    else if ((b & 0xF0) == 0xE0)   byteIdx += 3; // 3-byte character
    else if ((b & 0xF8) == 0xF0)   byteIdx += 4; // 4-byte character
    else                           byteIdx += 1; // Fallback for invalid bytes
    
    charCount++;
  }
  return -1; // Index out of bounds
}

// Copies the UTF-8 character pointed to by input buffer into the output buffer
bool copyChar(const char* startByte, char* destBuffer, int bufferSize) {

  unsigned char b = *startByte;
  int len = 1;
  // Identify sequence length from the leading byte
  if ((b & 0xE0) == 0xC0) len = 2;
  else if ((b & 0xF0) == 0xE0) len = 3;
  else if ((b & 0xF8) == 0xF0) len = 4;
  if (len + 1 > bufferSize) return false; // Buffer too small

  // Copy sequence and null-terminate
  memcpy(destBuffer, startByte, len);
  destBuffer[len] = '\0';
  return true;
}
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
void loop() {
//  char value;
  int ColTens;
  int ColOnes;
  char command[7] =     {0,0,0,0,0,0,0};
  int cpointer =        0;
  int tabcol;
  bool gotTabButton =   false;
  bool gotCRButton =    false;
  bool gotSpaceButton = false;
  
  while (1) {

    // first do a quick check for incoming command from PC
    // must be one of these these commands exactly
    //  LM xxx     
    //  RM xxx
    //  TS xxx
    //  TC xxx
    //  TABS =
    //  TYPE t
    //           xxx is three digit column number with leading zeroes if needed
    //           t is either N for normal or A for APL typeball
    while (Serial.available() > 0) {      // data available from serial port
      int j;
      command[cpointer++] = Serial.read();
      if (cpointer > 6) {
        Serial.print(ESC);
        Serial.print(OPEN);
        Serial.print(GREEN);
        Serial.print(END);
        Serial.print("input command ");
        Serial.print(command[0]);
        Serial.print(command[1]);
        Serial.print(command[2]);
        Serial.println(" too long, ignored");
        Serial.print(ESC);
        Serial.print(OPEN);
        if (RedRibbon == 1) {
          Serial.print(RED);
        } else {
          Serial.print(BLACK);
        }
        Serial.print(END);
        cpointer = 0;
      }
      if ((command [cpointer-1] == '\r') or (command[cpointer-1] == '\n')) {
        if (cpointer > 1) {
          Serial.print(ESC);
          Serial.print(OPEN);
          Serial.print(GREEN);
          Serial.print(END);
          Serial.print("short command ");
          Serial.println(" is ignored");
          Serial.print(ESC);
          Serial.print(OPEN);
          if (RedRibbon == 1) {
            Serial.print(RED);
          } else {
            Serial.print(BLACK);
          }
          Serial.print(END);
        }
        cpointer = 0;
      }
      if (cpointer == 6) {
        // command is complete, process it
        if ((command[0] == 'L') and (command[1] == 'M') and (command[2] == ' ')){
          tabcol = getcolumn(command,lmargin);
          if (tabcol > 0) {
            lmargin = tabcol;
            Serial.print(ESC);
            Serial.print(OPEN);
            Serial.print(GREEN);
            Serial.print(END);
            Serial.print("Left Margin set to "); Serial.println(lmargin);
            Serial.print('\r');
            Serial.print('\n');
            Serial.print(ESC);
            Serial.print(OPEN);
            if (RedRibbon == 1) {
              Serial.print(RED);
            } else {
              Serial.print(BLACK);
            }
            Serial.print(END);
            for (j = 1; j < lmargin; j++) {
              Serial.print(' ');
            }
            Cols = lmargin;         
          }   
        } else if ((command[0] == 'R') and (command[1] == 'M') and (command[2] == ' ')){
          tabcol = getcolumn(command,rmargin);
          if (tabcol > 0){
            rmargin = tabcol;
            Serial.print(ESC);
            Serial.print(OPEN);
            Serial.print(GREEN);
            Serial.print(END);
            Serial.print("Right Margin set to "); Serial.println(rmargin);
            Serial.print(ESC);
            Serial.print(OPEN);
            if (RedRibbon == 1) {
              Serial.print(RED);
            } else {
              Serial.print(BLACK);
            }
            Serial.print(END);
          }
        } else if ((command[0] == 'T') and (command[1] == 'Y') and (command[2] == 'P') and (command[3] == 'E') and (command[4] == ' ')){
          // set typeball to APL if TYPE A otherwise to normal if TYPE N
          if (command[5] == 'N') {
            aplball = 0;
            Serial.print(ESC);
            Serial.print(OPEN);
            Serial.print(GREEN);
            Serial.print(END);
            Serial.println("Using normal 969 typeball for 1053");
            Serial.print(ESC);
            Serial.print(OPEN);
            if (RedRibbon == 1) {
              Serial.print(RED);
            } else {
              Serial.print(BLACK);
            }
            Serial.print(END);
            zerobuffer();
            Cols = lmargin;
          } else if (command[5] == 'A') {
            aplball = 1;
            Serial.print(ESC);
            Serial.print(OPEN);
            Serial.print(GREEN);
            Serial.print(END);
            Serial.println("Using APL 988 typeball");
            Serial.print(ESC);
            Serial.print(OPEN);
            if (RedRibbon == 1) {
              Serial.print(RED);
            } else {
              Serial.print(BLACK);
            }
            Serial.print(END);
            zerobuffer();
            Cols = lmargin;         
          } else {
            Serial.print(ESC);
            Serial.print(OPEN);
            Serial.print(GREEN);
            Serial.print(END);
            Serial.print(command[5]);
            Serial.println(" is not a valid typeball");
            Serial.print(ESC);
            Serial.print(OPEN);
            if (RedRibbon == 1) {
              Serial.print(RED);
            } else {
              Serial.print(BLACK);
            }
            Serial.print(END);
          }
        } else if ((command[0] == 'T') and (command[1] == 'A') and (command[2] == 'B') and (command[3] == 'S') and (command[4] == ' ') and (command[5] == '=')){
          Serial.print(ESC);
          Serial.print(OPEN);
          Serial.print(GREEN);
          Serial.print(END);
          Serial.print("Tab stops are set at columns");
          int i;
          for (i = 0; i < 120; i++) {
            if (stops[i] == 1) {
              Serial.print(" "); Serial.print(i+1); 
            }
          }
          Serial.println('\n');
          Serial.print(ESC);
          Serial.print(OPEN);
          if (RedRibbon == 1) {
            Serial.print(RED);
          } else {
            Serial.print(BLACK);
          }
          Serial.print(END);
        } else if ((command[0] == 'T') and (command[1] == 'S') and (command[2] == ' ')){
          tabcol = getcolumn(command,0);
          if (tabcol > 0) {
            Serial.print(ESC);
            Serial.print(OPEN);
            Serial.print(GREEN);
            Serial.print(END);
            Serial.print("Tab set at column "); Serial.println(tabcol);
            Serial.print(ESC);
            Serial.print(OPEN);
            if (RedRibbon == 1) {
              Serial.print(RED);
            } else {
              Serial.print(BLACK);
            }
            Serial.print(END);
            updateStops(tabcol, 1);
          }
        } else if ((command[0] == 'T') and (command[1] == 'C') and (command[2] == ' ')){
          tabcol = getcolumn(command,0);
          if (tabcol > 0) {
            Serial.print(ESC);
            Serial.print(OPEN);
            Serial.print(GREEN);
            Serial.print(END);
            Serial.print("Tab cleared at column "); Serial.println(tabcol);
            Serial.print(ESC);
            Serial.print(OPEN);
            if (RedRibbon == 1) {
              Serial.print(RED);
            } else {
              Serial.print(BLACK);
            }
            Serial.print(END);
            updateStops(tabcol, 0);
          }
        } else {
          Serial.print(ESC);
          Serial.print(OPEN);
          Serial.print(GREEN);
          Serial.print(END);
          Serial.print(command[0]);
          Serial.print(command[1]);
          Serial.print(command[2]);
          Serial.println(" is not a valid command");
          Serial.print(ESC);
          Serial.print(OPEN);
          if (RedRibbon == 1) {
            Serial.print(RED);
          } else {
            Serial.print(BLACK);
          }
          Serial.print(END);
        }
        cpointer = 0;
      }
    }
    // emit bell sound if trying to pass the right margin and back up
    if (Cols > rmargin) {
      Serial.print('\a');
      Serial.print('\b');
      Cols = rmargin;
    }

    // we check for commands from 1130 system if idle
    if ((Cstate == Idle) and (Lstate == Idle)) {
      doT2 =          readT2;
      doT1 =          readT1;
      doR2A =         readR2A;
      doR1 =          readR1;
      doR2 =          readR2;
      doR5 =          readR5;
      doAux =         readAUX;
      doLineFeed =    readLF;
      doSpace =       readSP;
      doBackSpace =   readBSP;
      doTab =         readTAB;
      doCrLf =        readCRLF;
      doUpShift =     readUP;
      doDownShift =   readDN;
      doSpaceButton = readPBUT;
      doTabButton =   readTBUT;
      doCRButton =    readRBUT;
      doTabSet =      readSBUT;
      doTabClr =      readCBUT;
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

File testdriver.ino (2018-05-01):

//
// test driver to check out the PC1053 emulator of the 1053 console printer for an IBM 1130
//    
//    type any valid character on the typeball to cause it to print
//    enter special characters to cause these actions to be commanded:
//      spacebar to drive space
//      \ to backspace
//      ^ to tab
//      ` to feed one line down
//      ~ to do carrier return
//      [ to shift to upper case side of ball
//      ] to shift to lower case side of ball
//      { to shift to black ribbon
//      } to shift to red ribbon

#define SelectT2 22
#define SelectT1 24
#define SelectR2A 26
#define SelectR1 28
#define SelectR5 30
#define SelectR2 32
#define SelectAux 34
#define LineFeed 36
#define Tab 38
#define CrLf 40
#define UpShift 42
#define DownShift 44
#define Space 46
#define BackSpace 48
#define BlackShift 50
#define RedShift 52

// select code table
int Cselect[44] = {15, 6,  7, 12, 13,  4,  5,  9,  8, 31,
              22, 23, 28, 29, 20, 21, 25, 24, 38, 39,
              44, 45, 36, 37, 41, 40, 63, 54, 55, 60,
              61, 52, 53, 57, 56, 49, 48, 47, 33, 32,
              17, 16, 1, 0};
              
// Upper case character table
char Uchar[44] = {'A', 'B', 'C', 'D', 'E', 'F', 'G', 'H', 'I', 'J',
              'K', 'L', 'M', 'N', 'O', 'P', 'Q', 'R', 'S', 'T',
              'U', 'V', 'W', 'X', 'Y', 'Z', '(', '+', '<', 'n',
              ')', ';', '*', '\'', '"', '|', '=', '_', '?', ':', 
              '>', '!', '%', 'c'};
              
// Lower case character table
char Lchar[44] = {'A', 'B', 'C', 'D', 'E', 'F', 'G', 'H', 'I', 'J',
              'K', 'L', 'M', 'N', 'O', 'P', 'Q', 'R', 'S', 'T',
              'U', 'V', 'W', 'X', 'Y', 'Z', '1', '2', '3', '4',
              '5', '6', '7', '8', '9', '0', '#', '/', '-', ',', 
              '&', '$', '@', '.'};

void setup() {
  // put your setup code here, to run once:
  pinMode(SelectT1, OUTPUT);
  pinMode(SelectT2, OUTPUT);
  pinMode(SelectR1, OUTPUT);
  pinMode(SelectR2, OUTPUT);
  pinMode(SelectR2A, OUTPUT);
  pinMode(SelectR5, OUTPUT);
  pinMode(SelectAux, OUTPUT);
  pinMode(Space, OUTPUT);
  pinMode(BackSpace, OUTPUT);
  pinMode(BlackShift, OUTPUT);
  pinMode(RedShift, OUTPUT);
  pinMode(UpShift, OUTPUT);
  pinMode(DownShift, OUTPUT);
  pinMode(Tab, OUTPUT);
  pinMode(LineFeed, OUTPUT);
  pinMode(CrLf, OUTPUT);

  digitalWrite(SelectT1, HIGH);
  digitalWrite(SelectT2, HIGH);
  digitalWrite(SelectR1, HIGH);
  digitalWrite(SelectR2, HIGH);
  digitalWrite(SelectR2A, HIGH);
  digitalWrite(SelectR5, HIGH);
  digitalWrite(SelectAux, HIGH);
  digitalWrite(Space, HIGH);
  digitalWrite(BackSpace, HIGH);
  digitalWrite(BlackShift, HIGH);
  digitalWrite(RedShift, HIGH);
  digitalWrite(UpShift, HIGH);
  digitalWrite(DownShift, HIGH);
  digitalWrite(Tab, HIGH);
  digitalWrite(LineFeed, HIGH);
  digitalWrite(CrLf, HIGH);

  Serial.begin(9600);
  Serial.println("Ready for testing");
}

void loop() {
  char character;
  int i;
  int select;
  int doT1, doT2, doR1, doR2, doR2A, doR5;
  
  while (Serial.available() > 0) {
    character = Serial.read();

    if ((character == '\n') or (character == '\r')) {
      continue;
    }

    if (character == '~') {
      Serial.println("Firing CR");
      digitalWrite(CrLf, LOW);
      delay (15);
      digitalWrite(CrLf, HIGH);
      Serial.println(">");
      continue;
    } else if (character == '{') {
      Serial.println("Shifting to black portion of ribbon");
      digitalWrite(BlackShift, LOW);
      delay (15);
      digitalWrite(BlackShift, HIGH);
      Serial.println(">");
      continue;
    } else if (character == '}') {
      Serial.println("Shifting to red portion of ribbon");
      digitalWrite(RedShift, LOW);
      delay (15);
      digitalWrite(RedShift, HIGH);
      Serial.println(">");
      continue;
    } else if (character == '[') {
      Serial.println("Shifting to upper case side of typeball");
      digitalWrite(UpShift, LOW);
      delay (15);
      digitalWrite(UpShift, HIGH);
      Serial.println(">");
      continue;
    } else if (character == ']') {
      Serial.println("Shifting to lower case side of typeball");
      digitalWrite(DownShift, LOW);
      delay (15);
      digitalWrite(DownShift, HIGH);
      Serial.println(">");
      continue;
    } else if (character == '\\') {
      Serial.println("Backspacing one position");
      digitalWrite(BackSpace, LOW);
      delay (15);
      digitalWrite(BackSpace, HIGH);
      Serial.println(">");
      continue;
    } else if (character == ' ') {
      Serial.println("Spacing over one position");
      digitalWrite(Space, LOW);
      delay (15);
      digitalWrite(Space, HIGH);
      Serial.println(">");
      continue;
    } else if (character == '`') {
      Serial.println("Sending line feed");
      digitalWrite(LineFeed, LOW);
      delay (15);
      digitalWrite(LineFeed, HIGH);
      Serial.println(">");
      continue;
    } else if (character == '^') {
      Serial.println("Commanding a tab");
      digitalWrite(Tab, LOW);
      delay (15);
      digitalWrite(Tab, HIGH);
      Serial.println(">");
      continue;
    }

    if (isAlpha(character)) {
      String convert = " ";
      convert[0] = character;
      convert.toUpperCase();
      character = convert[0];
    }
    // try lower case first
    select = -1;
    for (i=0; i<44; i++) {
      if (Lchar[i] == character) {
        select = Cselect[i];
        break;
      }
    }
    if (select == -1) {
      for (i=0; i<44; i++) {
        if (Uchar[i] == character) {
          select = Cselect[i];
          break;
        }
      }
    }

    if (select == -1) {
      Serial.print(character);
      Serial.println(" is not a character on this typeball");
      continue;
    } else {
      Serial.print("Typing "); Serial.println(character);
    }

    // convert to the relevant signals
    doR5 = select & 0x01;
    doR2 = (select & 0x02) / 2;
    doR2A = (select & 0x04) / 4;
    doR1 = (select & 0x08) / 8;
    doT1 = (select & 0x10) / 16;
    doT2 = (select & 0x20) / 32;

    // fire up the tile/rotate and aux signals then wait for 8 ms
    if (doT1 == 1) {
      digitalWrite(SelectT1, LOW);
    }
    if (doT2 == 1) {
      digitalWrite(SelectT2, LOW);
    }
    delay(2);           // CVC temporary test of extreme skew
    if (doR1 == 1) {
      digitalWrite(SelectR1, LOW);
    }
    if (doR2 == 1) {
      digitalWrite(SelectR2, LOW);
    }
    if (doR2A == 1) {
      digitalWrite(SelectR2A, LOW);
    }
    if (doR5 == 1) {
      digitalWrite(SelectR5, LOW);
    }
    digitalWrite(SelectAux, LOW);

    delay(8);

    // switch off signals
    digitalWrite(SelectT1, HIGH);
    digitalWrite(SelectT2, HIGH);
    digitalWrite(SelectR1, HIGH);
    digitalWrite(SelectR2, HIGH);
    digitalWrite(SelectR2A, HIGH);
    digitalWrite(SelectR5, HIGH);
    digitalWrite(SelectAux, HIGH);

    // wait for cycle to complete
    delay(200);

    Serial.println(">");
    
  }
}

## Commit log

2026-05-19 Update README.md
    switch from relays (too slow) to MOSFET to drive feedback signals to 1130 system
2026-05-19 Switch from relay boards to MOSFET switches
    relays not fast enough to match 1053 I/O Selectric Typewriter
    [mosfet_board.kicad_sch]
2026-06-03 Version adding support for APL (988) typeball
    User can switch between the normal console typeball (969) used with the 1130 and the special APL typeball 988 when booting and using the APL for 1130 software.
    [codes.xlsx, mosfet_board.kicad_sch]
2026-06-03 UI improvements
    Better error messages and behavior with bad input
    [PC1053.ino]
2026-06-06 Updated schematic picture
    changed to match the current P-MOSFET version
2026-06-08 Minor fix
    Backskpace beyond left margin does nothing
    [PC1053.ino]
2026-06-10 New method to support APL composite characters
    Having been unable to get Putty to support Zero Width Joiner characters and merge characters into a composite glyph, I revamped the code to more directly produce the composites which do exist as unique glyphs in the APL 385 font. I look for cases where a sequence is typed of character A, a backspace and character B. Whether typed in that order or the reverse, eighteen known pairs of characters being overtyped by the APL software are detected and the composite glyph substituted for it.
    [PC1053.ino]
2026-06-10 Improved installation instructions
    Added several pictures of how the cables are connected and the orientation of the SMS paddle cards.
2026-06-11 Added log print program
    The Putty log file does not render colors or look exactly like what is on the screen when running the emulator. The program will ask the user to open the file and then displays it exactly as it showed on the Putty screen. Buttons allow paging forward or backward in page sizes (35 lines) as well as printing to the default printer on the Windows system.
    The user is also asked if they want to skip green text. The startup menu and any command sequence typed from Putty with emulator responses are written in green. This can be removed to show exactly what the 1053 would have shown on paper. If the user chooses no, then you also see the commands such as setting margins,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
2026-06-12 Cosmetic tweaks
    Ensure startup and menu are printed in green text
